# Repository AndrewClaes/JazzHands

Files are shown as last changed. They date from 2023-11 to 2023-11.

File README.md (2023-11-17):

# JazzHands
Home of the Hybrid Saxophone

This project is based around the SparkFun ESP32 Thing.
Following the instructions below,
you can equip any saxophone with extended programmable MIDI-output.
It has a control input and a standard DIN MIDI output. 
The controller can be battery powered and supports charging on 5V USB.

The system makes use of unipolar hall effect switches, mounted near the corresponding moving parts on the body of the saxophone.
Magnets are attached to the corresponding moving parts on the keywork.

Please visit 
https://www.instructables.com/Jazz-Hands-Hybrid-Saxophone/

more info:
https://andrewclaes.net

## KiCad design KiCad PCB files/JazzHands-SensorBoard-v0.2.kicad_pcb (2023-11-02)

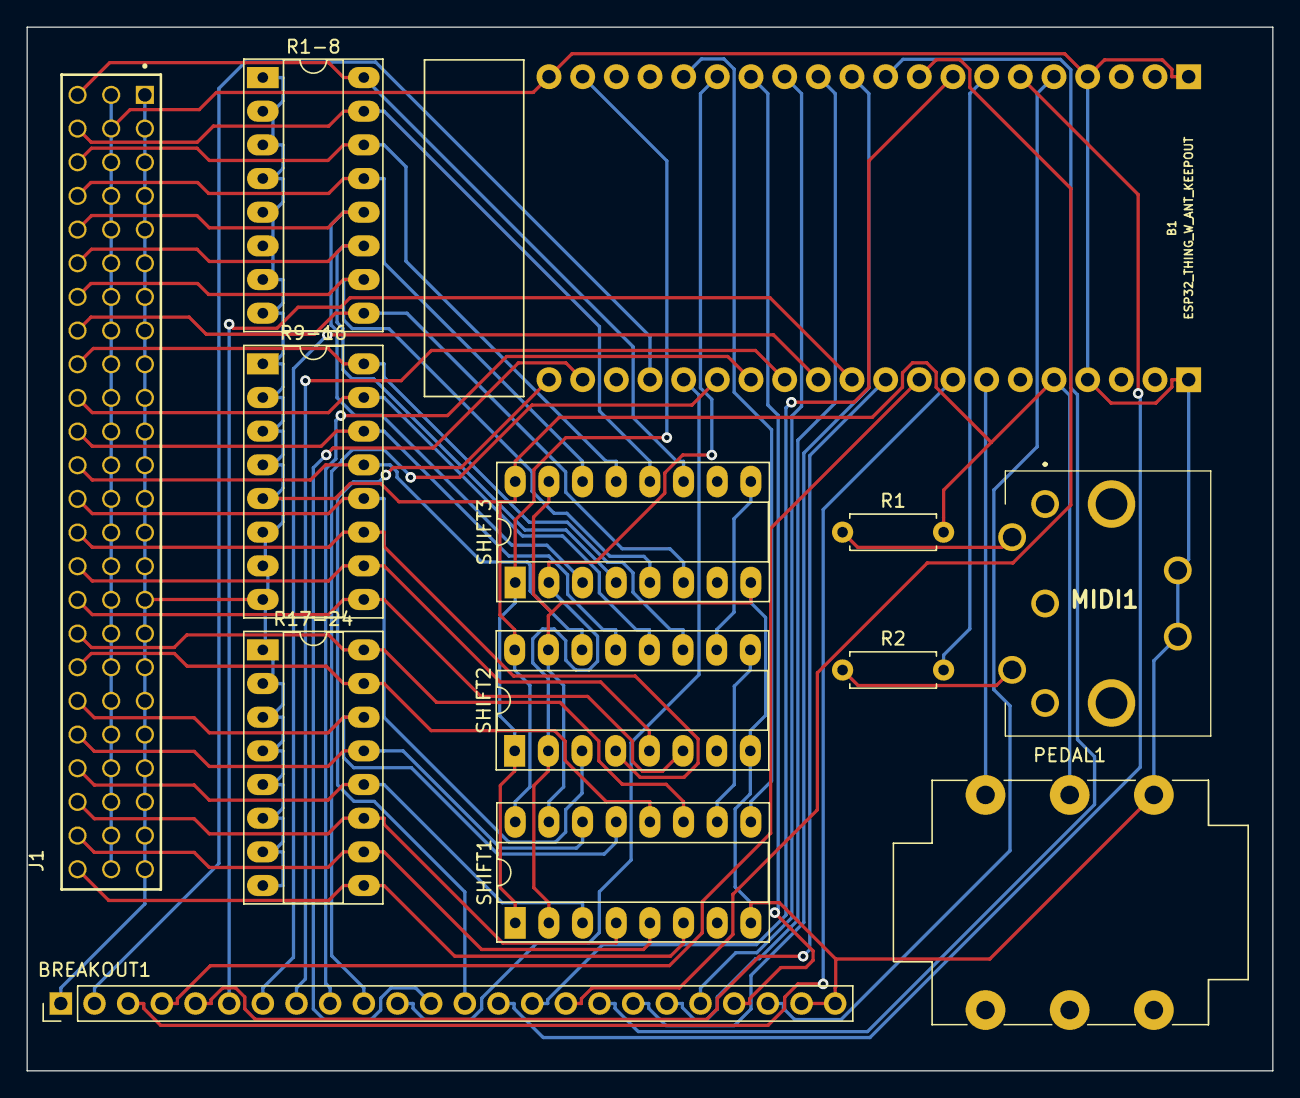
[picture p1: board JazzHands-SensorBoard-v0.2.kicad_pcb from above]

Board: 2 copper layers, 94.0 x 78.7 mm, 13 parts (0 on the bottom side), 56 nets.

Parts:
B1: ESP32_THING_W_ANT_KEEPOUT; ESP32_THING
BREAKOUT1: extra; PinHeader_1x24_P2.54mm_Vertical
J1: SSQ-124-01-T-T; SAMTEC_SSQ-124-01-T-T
MIDI1: 57PC5F
PEDAL1: AudioJack; Jack_6.35mm_Neutrik_NMJ6HCD2_Horizontal
R1, R2: 200; R_Axial_DIN0207_L6.3mm_D2.5mm_P7.62mm_Horizontal
R1-8, R9-16, R17-24: 100k; DIP-16_W7.62mm_Socket_LongPads
SHIFT1, SHIFT2, SHIFT3: 74HC165; DIP-16_W7.62mm_Socket_LongPads

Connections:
Earth: B1.1 (GND), B1.4 (GND), B1.21 (GND), B1.37 (GND), B1.40 (GND), BREAKOUT1.23, BREAKOUT1.24, J1.02, J1.05, J1.08, J1.11, J1.14, J1.17, J1.20, J1.23, J1.26, J1.29, J1.32, J1.35, J1.38, J1.41, J1.44, J1.47, J1.50, J1.53, J1.56, J1.59, J1.62, J1.65, J1.68, J1.71, MIDI1.6 (GND_1), MIDI1.7 (GND_2), PEDAL1.S, SHIFT1.8, SHIFT1.15, SHIFT2.8, SHIFT2.15, SHIFT3.8, SHIFT3.15
unnamed: B1.5 (3V3), BREAKOUT1.1, J1.01, J1.04, J1.07, J1.10, J1.13, J1.16, J1.19, J1.22, J1.25, J1.28, J1.31, J1.34, J1.37, J1.40, J1.43, J1.46, J1.49, J1.52, J1.55, J1.58, J1.61, J1.64, J1.67, J1.70, PEDAL1.R, R1.2, R1-8.1, R1-8.2, R1-8.3, R1-8.4, R1-8.5, R1-8.6, R1-8.7, R1-8.8, R9-16.1, R9-16.2, R9-16.3, R9-16.4, R9-16.5, R9-16.6, R9-16.7, R9-16.8, R17-24.1, R17-24.2, R17-24.3, R17-24.4, R17-24.5, R17-24.6, R17-24.7, R17-24.8, SHIFT1.16, SHIFT2.16, SHIFT3.16
unnamed: B1.8 (12), BREAKOUT1.3
unnamed: B1.9 (14), BREAKOUT1.4
unnamed: B1.10 (27), BREAKOUT1.5
unnamed: B1.11 (26), BREAKOUT1.6
unnamed: B1.12 (25), BREAKOUT1.7
unnamed: B1.13 (35), BREAKOUT1.8
unnamed: B1.14 (34), BREAKOUT1.9
unnamed: B1.15 (33), BREAKOUT1.10
unnamed: B1.16 (32), BREAKOUT1.11
unnamed: B1.17 (39), BREAKOUT1.2
unnamed: B1.19 (37), BREAKOUT1.12
unnamed: B1.20 (36), BREAKOUT1.13
unnamed: B1.22 (21), SHIFT1.1, SHIFT2.1, SHIFT3.1
unnamed: B1.25 (22), SHIFT1.9
unnamed: B1.26 (19), SHIFT1.2, SHIFT2.2, SHIFT3.2
unnamed: B1.27 (23), BREAKOUT1.21
unnamed: B1.28 (18), BREAKOUT1.20
unnamed: B1.29 (5), BREAKOUT1.19
unnamed: B1.30 (15), BREAKOUT1.18
unnamed: B1.31 (2), BREAKOUT1.17
unnamed: B1.32 (0), BREAKOUT1.16
unnamed: B1.33 (4), BREAKOUT1.15
unnamed: B1.34 (17), R2.2
unnamed: B1.35 (16), BREAKOUT1.14
unnamed: B1.36 (3V3), BREAKOUT1.22
unnamed: J1.03, R1-8.16, SHIFT3.11
unnamed: J1.06, R1-8.15, SHIFT3.12
unnamed: J1.09, R1-8.14, SHIFT3.13
unnamed: J1.12, R1-8.13, SHIFT3.14
unnamed: J1.15, R1-8.12, SHIFT3.3
unnamed: J1.18, R1-8.11, SHIFT3.4
unnamed: J1.21, R1-8.10, SHIFT3.5
unnamed: J1.24, R1-8.9, SHIFT3.6
unnamed: J1.27, R9-16.16, SHIFT2.11
unnamed: J1.30, R9-16.15, SHIFT2.12
unnamed: J1.33, R9-16.14, SHIFT2.13
unnamed: J1.36, R9-16.13, SHIFT2.14
unnamed: J1.39, R9-16.12, SHIFT2.3
unnamed: J1.42, R9-16.11, SHIFT2.4
unnamed: J1.45, R9-16.10, SHIFT2.5
unnamed: J1.48, R9-16.9, SHIFT2.6
unnamed: J1.51, R17-24.16, SHIFT1.11
unnamed: J1.54, R17-24.15, SHIFT1.12
unnamed: J1.57, R17-24.14, SHIFT1.13
unnamed: J1.60, R17-24.13, SHIFT1.14
unnamed: J1.63, R17-24.12, SHIFT1.3
unnamed: J1.66, R17-24.11, SHIFT1.4
unnamed: J1.69, R17-24.10, SHIFT1.5
unnamed: J1.72, R17-24.9, SHIFT1.6
unnamed: MIDI1.4, R1.1
unnamed: MIDI1.5, R2.1
unnamed: B1.7 (13), PEDAL1.T
unnamed: SHIFT1.10, SHIFT2.9
unnamed: SHIFT2.10, SHIFT3.9

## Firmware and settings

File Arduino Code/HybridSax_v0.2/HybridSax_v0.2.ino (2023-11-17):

/* JAZZHANDS Firmware v0.2
 *  
 */

#include <Arduino.h>
#include <BLEMidi.h>
#include <MIDI.h>

struct Serial2MIDISettings : public midi::DefaultSettings
{
  static const long BaudRate = 31250;
  static const int8_t RxPin  = 16;
  static const int8_t TxPin  = 17;
};

MIDI_CREATE_CUSTOM_INSTANCE(HardwareSerial, Serial2, DIN_MIDI, Serial2MIDISettings);

int myResult[24]; // Array with digital code of the sensorvalues

int noteSounding; // Current note
int getNote; // Is there a new note?

int programChange = 0;


//Note ON from PEDAL
int envValue;
int state;
unsigned long breath_on_time = 0L;
int initial_breath_value;
int atVal;
unsigned long atSendTime = 0L;
//PEDAL sound detector
#define NOTE_ON_THRESHOLD 80
#define MAX_PRESSURE 1000
#define NOTE_OFF 1
#define RISE_WAIT 2
#define NOTE_ON 3
#define AT_INTERVAL 70
#define RISE_TIME 2

// Octave sensor
int octaveKey = 23; 
int octave2Pin = 14;
int octave3Pin = 12;

int octaveValue = 0;



//Shift Register
const int dataPin = 22;   /* Shift Register Q7 */
const int clockPin = 19;  /* Shift Register CP */
const int latchPin = 21;  /* Shift RegisterPL */
const int numBits = 24;   /* Set to 8 * number of shift registers */

//PEDAL
#define INTERVAL 6   // time between reads
unsigned long lastRead = 0;
int pedalPin = 13;
int pedalValue = 0;
int pedalCC = 0;



void setup() {
  //Serial.begin(115200);
  //AD attenuation
  analogSetAttenuation(ADC_0db);
  //shift register
  pinMode(dataPin, INPUT);
  pinMode(clockPin, OUTPUT);
  pinMode(latchPin, OUTPUT);

  // BLE
  //Serial.println("Initializing bluetooth");
  BLEMidiServer.begin("HybridSax");
  //Serial.println("Waiting for connections...");

 //DIN_MIDI
  DIN_MIDI.begin(MIDI_CHANNEL_OMNI);
  
 //PEDAL
  pinMode(pedalPin, INPUT);
  

 //OCTAVES
 pinMode(octaveKey, INPUT_PULLUP);
 pinMode(octave2Pin, INPUT);
 pinMode(octave3Pin, INPUT);

 state = NOTE_OFF;
}
 
 int get_velocity(int initial, int final, unsigned long time_delta) {
     return map(final, NOTE_ON_THRESHOLD, MAX_PRESSURE,0,127);
     } 
 
 


 


void loop() {
  
  // Octaves
    // Check if octave hall switch is touched
  if (digitalRead(octaveKey) == HIGH) {
    octaveValue = 12;
  //  Serial.println(octaveValue);
  }
  if (digitalRead(octaveKey) == LOW) {
    octaveValue = 0;
    }
 
  // Check if octave2 sensor is touched
  if (touchRead(octave2Pin) < 30 && digitalRead(octaveKey) == LOW) {
      octaveValue = -12;
      }
  // Check if octave2 and octave3 sensors are touched
  if (touchRead(octave2Pin) < 30 && touchRead(octave3Pin) < 30) {
      octaveValue = -24;
      }
  // Check if octave3 sensor is touched
  else if (touchRead(octave3Pin) < 30 && digitalRead(octaveKey) == LOW) {
      octaveValue = -36;
      }
 
 
  //PEDAL
  if (millis() - lastRead >= INTERVAL){  // if INTERVAL has passed
      pedalValue = analogRead(pedalPin);
      lastRead = millis(); 
      pedalCC = map(pedalValue,0,4096,0,127);
      //Serial.println(pedalCC);
      DIN_MIDI.sendControlChange(2, pedalCC, 1);
      if(BLEMidiServer.isConnected()) {
         BLEMidiServer.controlChange(0, 2, pedalCC);
         }
  }
  
  
  
  // Shift Register Step 1: Sample
  digitalWrite(latchPin, LOW);
  digitalWrite(latchPin, HIGH);

  // Shift Register Step 2: Shift
  for (int i = 0; i < numBits; i++) {
    int bit = digitalRead(dataPin);
    if (bit == HIGH) {
      myResult[i] = 0;
      
    } else {
      myResult[i] = 1;
    }
    digitalWrite(clockPin, HIGH); // Shift out the next bit
    digitalWrite(clockPin, LOW);
  }
   // Construct a 24 bit value from the sensors
   uint32_t value = (myResult[0] << 23) +
                      (myResult[1] << 22) +
                      (myResult[2] << 21) +
                      (myResult[3] << 20) +
                      (myResult[4] << 19) +
                      (myResult[5] << 18) +
                      (myResult[6] << 17) +
                      (myResult[7] << 16) +
                      (myResult[8] << 15) +
                      (myResult[9] << 14) +
                      (myResult[10] << 13) +
                      (myResult[11] << 12) +
                      (myResult[12] << 11) +
                      (myResult[13] << 10) +
                      (myResult[14] << 9) +
                       (myResult[15] << 8) + 
                       (myResult[16] << 7) +
                       (myResult[17] << 6) +
                       (myResult[18] << 5) +
                       (myResult[19] << 4) +
                       (myResult[20] << 3) +
                       (myResult[21] << 2) +
                       (myResult[22] << 1) +
                       myResult[23];

// DEBUG: print all sensor states                    
//  Serial.println(value);
//   for (int i = 0;i < 24;i++){
//    Serial.print(myResult[i]);
//  }
//  Serial.println(); 
  

  // Define the notes from the sensors
  #define BASE 73 + octaveValue
  switch (value) {
    case 492984: //C
      getNote = BASE + 11;
      break;

    case 501176: //B
      getNote = BASE + 10;
      break;

    case 505272: //Bb
       getNote = BASE + 9;
       break;

    case 505784: //A
      getNote = BASE + 8;
      break;

    case 261448: //G#
      getNote = BASE + 7;
      break;

    case 440648: //G
      getNote = BASE + 6;
      break;

    case 458568: //F#
       getNote = BASE + 5;
       break;

    case 196936: //F
      getNote = BASE + 4;
      break;

    case 229704: //E
      getNote = BASE + 3;
      break;

    case 491848: //D#
      getNote = BASE + 2;
      break;

    case 500040: //D
       getNote = BASE + 1;
       break;

    case 504136: //C# BASE
       getNote = BASE;
       break;

    case 505672: //C
      getNote = BASE - 1;
      break;
      
    case 506184: //B
      getNote = BASE - 2;
      break;
    
    case 507208: //Bb
      getNote = BASE - 3;
      break;

    case 442184: //Bb alternate
      getNote = BASE - 3;
      break;
    
    case 507720: //A
      getNote = BASE - 4;
      break;

    case 507592: //G#
      getNote = BASE - 5;
      break;
    
    case 507848: //G
      getNote = BASE - 6;
      break;
    
    case 507880: //F#
      getNote = BASE - 7;
      break;
    
    case 524232: //F
      getNote = BASE - 8;
      break;
    
    case 524264: //E
      getNote = BASE - 9;
      break;

    case 524216: //Eb
      getNote = BASE - 10;
      break;

    case 524280: //D
      getNote = BASE - 11;
      break;

    case 524276: //C#
       getNote = BASE - 12;
       break;

    case 524284: //C
      getNote = BASE - 13;
      break;

    case 524286: //B
      getNote = BASE - 14;
      break;

    case 524287: //Bb
      getNote = BASE - 15;
      break;

    case 373064: // Program Change UP
      programChange = programChange + 1;
      DIN_MIDI.sendProgramChange(programChange, 1);
      delay(500);
      break;

    case 438600: // Program Change DOWN
      programChange = programChange - 1;
      if(programChange < 0){
        programChange = 0;
      }
      DIN_MIDI.sendProgramChange(programChange, 1);
      delay(500);
      break;
      
   
    default:
      getNote = noteSounding;
  }

  
  //  send MIDI
   envValue = pedalValue;
   if (state == NOTE_OFF) {
       if (envValue > NOTE_ON_THRESHOLD) {
       // Value has risen above threshold. Move to the RISE_TIME
       // state. Record time and initial breath value.
          breath_on_time = millis();
          initial_breath_value = envValue;
          state = RISE_WAIT;  // Go to next state
          }
  } else if (state == RISE_WAIT) {
    if (envValue > NOTE_ON_THRESHOLD) {
      // Has enough time passed for us to collect our second
      // sample?
      if (millis() - breath_on_time > RISE_TIME) {
        // Yes, so calculate MIDI note and velocity, then send a note on event
        noteSounding = getNote;
        int velocity = get_velocity(initial_breath_value, envValue, RISE_TIME);
        DIN_MIDI.sendNoteOn(noteSounding,velocity*5,1);
        if(BLEMidiServer.isConnected()) {               
          BLEMidiServer.noteOn(0, noteSounding, velocity); 
          }
        state = NOTE_ON;
      }
    } else {
      // Value fell below threshold before RISE_TIME passed. Return to
      // NOTE_OFF state (e.g. we're ignoring a short blip of breath)
      state = NOTE_OFF;
    }
  } else if (state == NOTE_ON) {
    if (envValue < NOTE_ON_THRESHOLD) {
      // Value has fallen below threshold - turn the note off
      DIN_MIDI.sendNoteOff(noteSounding,0,1);  
      if(BLEMidiServer.isConnected()) {
           BLEMidiServer.noteOff(0,noteSounding, 0);
           }
       
      state = NOTE_OFF;
    } else {
      // Is it time to send more aftertouch data?
      if (millis() - atSendTime > AT_INTERVAL) {
        // Map the sensor value to the aftertouch range 0-127
        atVal = map(envValue, NOTE_ON_THRESHOLD, 4096, 0, 127);
        DIN_MIDI.sendControlChange(2, atVal, 1);
        if(BLEMidiServer.isConnected()) {
         BLEMidiServer.controlChange(0, 2, atVal);
         }          
        atSendTime = millis();
      }
    }
  
  if (millis() - lastRead >= INTERVAL){  // if INTERVAL has passed
      lastRead = millis(); 
      int newNote = getNote;
      if (newNote != noteSounding){
          //Serial.println("noteoff:");
          //Serial.println(noteSounding);
          DIN_MIDI.sendNoteOff(noteSounding,0,1); 
          if(BLEMidiServer.isConnected()) {
             BLEMidiServer.noteOff(0,noteSounding, 127);
             }
          noteSounding = newNote;
          //Serial.println("noteon:");
          //Serial.println(noteSounding);
          DIN_MIDI.sendNoteOn(noteSounding, 127,1);
          if(BLEMidiServer.isConnected()) {               
             BLEMidiServer.noteOn(0, noteSounding, 127); 
             }
          
           
  }
 }
 }
} 



   
     
   

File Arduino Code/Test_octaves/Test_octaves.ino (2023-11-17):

/* JAZZHANDS Touch Sensors Test
 *  
 */

#include <Arduino.h>
// Octave sensor
int octaveHall = 23;
int octave2Pin = 12;
int octave3Pin = 14;


void setup() {
  Serial.begin(115200);
 

 //OCTAVES
 pinMode(octaveHall, INPUT_PULLUP);
 pinMode(octave2Pin, INPUT);
 pinMode(octave3Pin, INPUT);

 }



void loop() {
  if (digitalRead(octaveHall) == HIGH) {
      Serial.println("octave Hall is off");
      }
  if (digitalRead(octaveHall) == LOW) {
      Serial.println("octave Hall is on");
      }
  
  if (touchRead(octave2Pin) < 30) {
      Serial.println("touchsensor1 is working");
      }
  else if (touchRead(octave3Pin) < 30) {
      Serial.println("touchsensor2 is working");
      }
 
}

   
     
   
